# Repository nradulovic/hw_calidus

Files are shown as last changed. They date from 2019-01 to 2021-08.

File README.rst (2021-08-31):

.. contents:: Table of Contents
   :depth: 3

Introduction
============

This document shall describe rationales used to design and build audio
power amplifier using TDA7293 integrated circuit.

Architecture
============

The amplifier architecture consists of the following sections:

* Input section
* Output section
* Power amplifier with power supply and Control and Monitoring Unit (CMU)

Input section
=============

Input EMI suppression
---------------------

To protect the input from EMI we will use the following Zobel network:

.. code::
          o Positive input or negative input
          |
          |
        ----- Czi
        -----
          |
          |
         +-+  Rzi
         | |
         | |
         +-+
          |
         === Ground

For most input cables characteristic impedance falls in range between
50 and 100ohm impedance and we are using the 75ohm as the middle value. The
resistor Rzi is ``Rzi=75ohm`` and the capacitor Czi is ``Czi=220pF``.
This network should be placed right at the input connector, not on the
main amplifier PCB.

Also, a 100n X7R capacitor shall be placed between SGND and chassis right at the
input connector. This capacitor will shunt radio and other interfirence signal
into the Chassis Ground potential.

Input low-pass filter
---------------------

For input filter we choose the frequency between 300kHz and 400kHz.

.. code::

        +---+ Rlp1    +---+ Rlp2
    0---+   +----+----+   +---+---o Toward Amplifier IC block
        +---+    |    +---+   |
               ----- Clp1   ----- Clp2
               -----        -----
                 |            |
                === Ground   === Ground

Using the 2nd order CR low-pass filter calculator at URL:
*http://sim.okawa-denshi.jp/en/CRCRtool.php* we arrive at:

.. math::

    Rlp1 = 100 Ohm, Rlp2 = 100 Ohm

    Clp1 = 220pF,   Clp2 = 2.2nF

    fp1 = 352kHz

    fp2 = 14MHz

For more details please refer to: http://www.johnhearfield.com/RC/RC4.htm

The ground loop breaker resistor
--------------------------------

A ground loop breaker resistor is located between SGND and GNDPWR grounds. The
value of this resistor should be around 10 ohms.

Power amplifier
===============

Output EMI suppression
----------------------

Output network consists of upstream and downstream Zobel Network and of output
coil (``Ld``) with parallel, damping resistor (``Rd``). Upstream Zobel network 
provides a low-inductance load for the output stage at very high frequencies 
and allows high-frequency currents to circulate local to the output stage. The 
downstream Zobel network provides a good resistive termination right at the 
speaker terminals at high frequencies, helping to reduce RFI ingress and damp
resonances with, or reflections from, the speaker cables.
The output circuit is the following:

.. code::

    Ld
             xxx
        +---x   x   x---+
        |        xxx    |
        |               |
        |   +-------+   |
    o---+---|       |---+---o
    Vout    +-------+   |   Vspeaker
        Rd              |
                      ----- Cz2 = 100nF
                      -----
                        |
                        |
                       +-+  Rz1 = 10 Ohm
                       | |
                       | |
                       +-+
                        |
                       ===

The output coil ``Ld`` provides high frequency isolation of output load from 
output stage in TDA7293. The inductance value should be between 2uH up to 5uH.
Output shunt resistor should be between 2 and 5 Ohms. See
*Douglas Self - Audio Power Amplifier Design Handbook, 3rd Ed., Output networks, chapter 7*
for effect on power amplifier transfer function.

Paralleling multiple modules
----------------------------

Power dissipation
`````````````````

NOTE:

* Try to keep power dissipation to around 40W per IC package.

Fortunately, with music signals the power dissipation should be lower.
Effective power of music signal is about 2 to 10 times as smaller than
effective power of sinusoid signal. The power transformer is 200VA, meaning
that each channel gets 100VA of power.

Maximum voltages at:
 * Maximum ``Pdiss=50W`` for TDA7293.
 * Load phase is ``LoadPHI=60degrees``.
 * Including quiescent current dissipation.
 * Case temperature is 60C degrees.
 * Taking into account OPS SOA.

+-------------+-------------+-----------+--------------+
| Zload [ohm] | Vsupply [V] | Vdrop [V] | Pdiss [W]    |
+-------------+-------------+-----------+--------------+
| 16          | 33          | 2.2       | 31.4         |
+-------------+-------------+-----------+--------------+
| 12          | 29          | 2.3       | 31.6         |
+-------------+-------------+-----------+--------------+
| 8           | 25          | 2.5       | 34.2         |
+-------------+-------------+-----------+--------------+
| 6           | 22          | 2.6       | 34.7         |
+-------------+-------------+-----------+--------------+
| 4           | 19          | 2.9       | 37.4         |
+-------------+-------------+-----------+--------------+

This table tells us that if we want to drive 4ohm load at 33V we need 4 pieces
of TDA7293 in parallel. This is quite a number of ICs, but fortunately, the
table presumes that the power supply can produce constant 33V at continuous
load and the signal is sinusoid. This is not the case with unregulated power
supply and music signals. We have to take into account how much energy is
stored in power supply capacitors and how much will the transformer voltages
sag under these conditions and that music signal has much lower effective power
comparing to instantaneous power.

Transformer specification for TDA7293 amplifier is the following:
 * ``S=200VA``, power rating.
 * ``Usn1=24Veff``, first secondary nominal voltage.
 * ``Usn2=24Veff``, second secondary nominal voltage.
 * ``k=5%``, regulation.

Secondary internal resistance is:

.. math::

    Usu=Usn1*(1+(k/100))

    Isn=S/(Usn1+Usn2)

    Ri=(Usn1-Usu)/Isn

Using values from above we get:

.. math::

    Usu=24*(1+(5/100))=25.2Veff

    Isn=4.17Aeff

    Ri=288mOhm

The power supply section is using single bank of 10mF capacitors.

Gain value
----------

Using inverted topology since we want to reduce common mode distortion in the
input stage. But in case of TDA7293 IC it is not easy to use inverted topology
since the mute circuit is implemented on positive OPAMP input.

The equivalent gain circuit resistance needs to stay below 600ohms. This is so
because all noise measurements in data-sheet were done with 600ohms or 0ohms.

Using low feedback gain is preferred for several reasons:
 * there is more loop gain available to reduce the distortion
 * reduced outout noues
 * lower offset at output

Nominal gain is:

.. math::

    G=-Rf/Rg

Using E24 series of resistors:

+-----------+-----------+---------+
| Rf [Ohm]  | Rg [kOhm] | G [V/V] |
+-----------+-----------+---------+
| 510       |  7.5      | -14.7   |
+-----------+-----------+---------+
| *510*     |  *8.2*    | *-16.0* |
+-----------+-----------+---------+
| 510       |  9.1      | -17.8   |
+-----------+-----------+---------+
| 510       | 10.0      | -19.6   |
+-----------+-----------+---------+
| 510       | 11.0      | -21.5   |
+-----------+-----------+---------+

Using E24 series of resistors:

+-----------+-----------+---------+
| Rf [Ohm]  | Rg [kOhm] | G [V/V] |
+-----------+-----------+---------+
| 511       |  7.50     | -14.7   |
+-----------+-----------+---------+
| 511       |  7.87     | -15.4   |
+-----------+-----------+---------+
| *511*     |  *8.25*   | *-16.1* |
+-----------+-----------+---------+
| 511       |  8.66     | -16.9   |
+-----------+-----------+---------+
| 511       |  9.09     | -17.8   |
+-----------+-----------+---------+
| 511       |  9.53     | -18.6   |
+-----------+-----------+---------+
| 511       | 10.00     | -19.6   |
+-----------+-----------+---------+
| 511       | 10.50     | -20.5   |
+-----------+-----------+---------+
| 511       | 11.00     | -21.5   |
+-----------+-----------+---------+

Chosen values for E24 series:
 * Rf = 8.2kOhm
 * Rg = 510 Ohm

Chosen values for E48 series:
 * Rf = 8.25kOhm
 * Rg = 511 Ohm

Chosen values when using parallel E24 series (two resistor):
 * Rf = 16kOhm
 * Rg = 1kOhm

Chosen values when using parallel E48 series (two resistor):
 * Rf = 16.2kOhm
 * Rg = 1kOhm

Frequency compensation
----------------------

The TDA7293 data-sheet does not provide enough of relevant data in order to
model the IC in AC domain. Since we can't model it there are no optimizations
available for the negative feedback circuit. But we can safely assume that
there are high frequency poles present in the TDA7293 transfer function. For
this reason we will add a few ``pF`` to calculated lead compensation
capacitor below (see ``Cadd``).

Lead compensation
`````````````````

Equivalent feedback network with lead compensation circuit::

          o Vout
          |
          *------+
          |      |
         +-+ Rf  |
         | |   ----- Cf=Cl (+Csi, see Input pin capacitance compensation)
         | |   -----
         +-+     |
   Vf     |      |
    o-----*------+
          |
         +-+ Rg
         | |
         | |
         +-+
          |
          o Input

Resistors `Rf` and `Rg` are part of feedback network. Capacitor `Cf` is the
compensation capacitor. The transfer function of this network is given as:

.. math::

    Vf(s)=I(s)*Rg

    Vout(s)=I(s)*(Rf||Cl + Rg)=I(s)*(Rf/(1+s*Rf*Cl)+Rg)

    H(s)=Vf(s)/Vout(s)=(Rg/(Rf+Rg))*((1+s*Rf*Cl)/(1+s*Re*Cl))

Zero:

.. math::

    wz=1/(Rf*Cl)

Pole:

.. math::

    wp=1/(Re*Cl)

Where:

.. math::

    Re=Rf||Rg=Rf*Rg/(Rf+Rg)

Rough estimation is to put additional 1-3pF in parallel to ``Rf``.

.. math::

	Cadd = 3pF

Input pin capacitance compensation
``````````````````````````````````

Input pins have the following parasitic capacitances associated:

* Cdiff
* Cm
* Cstray

The TDA7293 data-sheet does not specify any parameter regarding parasitic
input capacitances. Voltage feedback OPAMPS usually have both differential and
common-mode input impedances specified. In the absence of any information, it
is safe to use the model given in the next figure:

.. code::

                   +----+ Zdiff
    +input o---+---|    |---+---o -input
               |   +----+   |
               |            |
              +-+ Zcm1     +-+ Zcm2
              | |          | |
              | |          | |
              +-+          +-+
               |            |
              ===          ===

We can use a rough estimation of values based on experience on using other 
audio FET OPAMPS, and typical values are around ``Cdiff=5pF``, ``Cm=4pF`` 
and ``Cstray=3pF``. All three equivalent capacitors are tied in parallel, 
so the total input capacitance becomes:

.. math::

    Cinput = Cdiff+Cm+Cstray=5pF+4pF+3pF=12pF

To mitigate this capacitance we can add capacitance `Csi` parallel to `Rf`
resistor. To compensate for this the following equation is applied:

.. math::

    Rf*Cf=Rg*Cinput

    Csi=Cinput*Rg/Rf=0.5pF

The final ``Cf`` value is:

.. math::

    Cf=Cl+Csi+Cadd=0+2+0.5=2.5pF

Any NP0 based capacitor around ``3pF`` will be good for this purpose.

Power supply
============

Power amplifier power supply
----------------------------

We are using dual symmetrical supplies from since dual secondaries. The high
voltage supplies are stabilized using LM317/LM337 regulators and are used to
feed input sections of TDA7293.

The low voltage supplies are supplied directly from reservoir capacitors. This
supply powers the high current, high power output sections of TDA7293.

By using dual and independent supplies for input sections and power sections we
can achieve very good PSRR results.

Before rectifier diodes a snubber RC circuit should be placed to decrease diode
switching impulse. Recommended values are ``Rsn = 1 Ohm``, ``Csn = 470nF``::

          o Vsupply
          |
          |
        ----- Csn = 470nF
        -----
          |
          |
         +-+  Rsn = 1 Ohm
         | |
         | |
         +-+
          |
         === Ground

This snubber may be placed near the IC power supply lines, too.

AC mains
--------

NOTE:
 * On case chassis there should be a safety ground screw just near at the input
   220V socket.

Control and Monitoring Unit
===========================

Amplifier controller will control and monitor two amplifiers. It has the
following components:

* Power supply undervoltage protection
* Power supply overvoltage protection
* Power supply imbalance protection
* Output DC offset protection
* Output clipping protection
* Over-temperature protection
* Over-current protection

Power supply undervoltage protection
------------------------------------

Power supply overvoltage protection
-----------------------------------

Power supply imbalance protection
---------------------------------

Output DC offset protection
---------------------------

Output clipping protection
--------------------------

Over-temperature protection
---------------------------

Over-current protection
-----------------------

Analog inputs
-------------

.. code::

                o  Vdd
                |
               +-+
               | | R2
               | |
         R1    +-+
        +---+   |
    o---|   |---+------+---o Analog output (to MCU ADC)
        +---+   |      |
    Analog     +-+     |
    Input      | | R3 --- C1
               | |    ---
               +-+     |
                |      |
               ===    ===

Enviromental parametars:

* Power supply: Vdd = 5V
* Analog output impedance: Rout <= 10k

Specification:

* Analog input range: Ain = +/-40V
* Analog input impedance: Rin >= 10k

Equations:
 (1) Since for 0V Ain we need 2.5V Aout: R2 = R1 || R3
 (2) Since we need gain 1/16 (5V/80V) we have: 16 = R1 / (R1 || R2 || R3)

This give as two equations with 3 unknowns:

.. math::

    (1 - Gain - 1)*G1 + G2 + G3 = 0

    Vref * G1 + Vref * G2 + (Vref - Vhigh) * G3 = 0

With Gain = 16, Vreg = 2.5V and Vhigh = 5V we have:

.. math::

    -15G1+G2+G3=0

    2.5G1+2.5G2-2.5G3=0

Start with G3 = 1/10:

.. math::

    -15G1+G2=-0.1

    2.5G1+2.5G2=0.25

    G1=1.25e+3 => R1=80kOhm

    G3=8.75e-2 => R2=11.43kOhm

One possibility is to have:

.. math::

    R1 = 110kOhm

    R2 = 10kOhm

    R3 = 11kOhm

This combination has Gain = 22

Monitor PIC18F46K40/PIC18F26K40 MCU pins
----------------------------------------

+-----------------------+---------------+-----------+-----------+---------------------------------------------------+
| # / Signal name       | Type          | 40 pin    | 28 pin    | Description                                       |
+-----------------------+---------------+-----------+-----------+---------------------------------------------------+
| 1. pa_vcc             | analog in     | RD0       |           | Measures the VCC voltage                          |
+-----------------------+---------------+-----------+-----------+---------------------------------------------------+
| 2. pa_vee             | analog in     | RD1       |           | Measures the VEE voltage                          |
+-----------------------+---------------+-----------+-----------+---------------------------------------------------+
| 3. pa_ope             | analog in     | RA6       | RA6       | Measures Output Positive Envelope (Both channels) |
+-----------------------+---------------+-----------+-----------+---------------------------------------------------+
| 4. pa_one             | analog in     | RA7       | RA7       | Measures Output Negative Envelope (Both channels) |
+-----------------------+---------------+-----------+-----------+---------------------------------------------------+
| 5. pa_oal             | analog in     | RA2       | RA2       | Measures Output Average Left                      |
+-----------------------+---------------+-----------+-----------+---------------------------------------------------+
| 6. pa_oar             | analog in     | RA4       | RA4       | Measures Output Average Right                     |
+-----------------------+---------------+-----------+-----------+---------------------------------------------------+
| 7. pc_ol              | analog/comp in| RA0       | RA0       | Compares Output Left impedance                    |
+-----------------------+---------------+-----------+-----------+---------------------------------------------------+
| 8. pc_or              | analog/comp in| RA1       | RA1       | Compares Output Right impedance                   |
+-----------------------+---------------+-----------+-----------+---------------------------------------------------+
| 9. pc_ref             | analog/comp in| RA3       | RA3       | Comparator reference voltage                      |
+-----------------------+---------------+-----------+-----------+---------------------------------------------------+
| 10. pc_i2c_scl        | i2c scl       | RC3       | RC3       | Sensor network SCL                                |
+-----------------------+---------------+-----------+-----------+---------------------------------------------------+
| 11. pc_i2c_sda        | i2c sda       | RC4       | RC4       | Sensor network SDA                                |
+-----------------------+---------------+-----------+-----------+---------------------------------------------------+
| 12. pc_uart_rx        | uart rx       | RC7       | RC7       | Service terminal RX (from PIC perspective)        |
+-----------------------+---------------+-----------+-----------+---------------------------------------------------+
| 13. pc_uart_tx        | uart tx       | RC6       | RC6       | Service terminal TX (from PIC perspective)        |
+-----------------------+---------------+-----------+-----------+---------------------------------------------------+
| 14. po_comp_en        | dig out       | RA5       | RA5       | Enable comparator current sources                 |
+-----------------------+---------------+-----------+-----------+---------------------------------------------------+
| 15. po_ctrl_power     | dig out       | RB1       | RB1       | Control power relay                               |
+-----------------------+---------------+-----------+-----------+---------------------------------------------------+
| 16. po_ctrl_pbypass   | dig out       | RB2       | RB2       | Control power bypass relay                        |
+-----------------------+---------------+-----------+-----------+---------------------------------------------------+
| 17. po_ctrl_mute      | dig out       | RB3       | RB3       | Control mute relay                                |
+-----------------------+---------------+-----------+-----------+---------------------------------------------------+
| 18. po_ctrl_enable    | dig out       | RB4       | RB4       | Control power amplifier enable                    |
+-----------------------+---------------+-----------+-----------+---------------------------------------------------+
| 19. po_ind_power_a    | dig out       | RB5       | RB5       | Indicator power/status LED, pin A                 |
+-----------------------+---------------+-----------+-----------+---------------------------------------------------+
| 20. po_ind_power_b    | dig out       | RD2       |           | Indicator power/status LED, pin B                 |
+-----------------------+---------------+-----------+-----------+---------------------------------------------------+
| 21. po_ind_overload   | dig out       | RB6       | RB6       | Indicator overload LED                            |
+-----------------------+---------------+-----------+-----------+---------------------------------------------------+
| 22. po_status         | dig out       | RB7       | RB7       | Status LED on board                               |
+-----------------------+---------------+-----------+-----------+---------------------------------------------------+
| 23. pi_key_power      | dig in        | RB0       | RB0       | Power key                                         |
+-----------------------+---------------+-----------+-----------+---------------------------------------------------+
| 24. pi_key_mute       | dig in        | RC5       | RC5       | Mute key                                          |
+-----------------------+---------------+-----------+-----------+---------------------------------------------------+
| 25. pi_det_ac_power   | dig in        | RC0       | RC0       | AC power detection                                |
+-----------------------+---------------+-----------+-----------+---------------------------------------------------+
| 26. pi_det_overload   | dig in        | RC1       | RC1       | Overload detection                                |
+-----------------------+---------------+-----------+-----------+---------------------------------------------------+
| 27. pi_det_signal     | dig in        | RC2       | RC2       | Signal detection                                  |
+-----------------------+---------------+-----------+-----------+---------------------------------------------------+
| 28. pi_cfg_power      | dig in        | RD3       |           | Configure power control mode                      |
+-----------------------+---------------+-----------+-----------+---------------------------------------------------+
| 29. pi_cfg_ac_power   | dig in        | RD4       |           | Configure AC power detection mode                 |
+-----------------------+---------------+-----------+-----------+---------------------------------------------------+
| 30. pi_cfg_impedance  | dig in        | RD5       |           | Configure Impedance monitoring mode               |
+-----------------------+---------------+-----------+-----------+---------------------------------------------------+
| 31. pi_cfg_sensors    | dig in        | RD6       |           | Configure sensors mode                            |
+-----------------------+---------------+-----------+-----------+---------------------------------------------------+
| 32.                   |               | RD7       |           |                                                   |
+-----------------------+---------------+-----------+-----------+---------------------------------------------------+
| 33.                   |               | RE0       |           |                                                   |
+-----------------------+---------------+-----------+-----------+---------------------------------------------------+
| 34.                   |               | RE1       |           |                                                   |
+-----------------------+---------------+-----------+-----------+---------------------------------------------------+
| 35.                   |               | RE2       |           |                                                   |
+-----------------------+---------------+-----------+-----------+---------------------------------------------------+

Hardware configurations
-----------------------

Power control mode

* 0 - Disabled, always on
* 1 - Enabled, wait for Power on event

AC power detection mode:

* 0 - Disabled, AC always present
* 1 - Enabled, AC detect on

Impedance monitoring mode:

* 0 - Disabled, always allow power on
* 1 - Enabled, dissallow power on when impedance is out of minimal limit

Sensors mode:

* 0 - Disabled, all temperature sensors are ignored
* 1 - Enabled, read all temperature sensors

Software configurations
-----------------------

Power supply:

* nominal value: 20V
* minimal value: 15V
* maximum value: 25V
* imbalance value: 10V
* bypass time: 500ms
* post bypass time: 500ms
* mode, same as HW configuration 1

Clipping detector:

* clipping min voltage 4: 5
* clipping min voltage 8: 3
* hold off: 1000ms
* timeout to mute: 10s
* timeout to shutdown: 20s
* mode:

  * 0 - Disabled,
  * 1 - Enabled

AC detector:

* num of cycles missing: 4
* mode, same as HW configuration 2

Impedance detector:

* mode, same as HW configuration 3

Temperature detector:

* mode

Chassis
=======

Component height
----------------

Power supply capacitors on amplifier boards:

* 30mm (10mF)

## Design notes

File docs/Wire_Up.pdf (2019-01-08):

# How to Wire up an Audio Power Amplifier for Zero Noise Problems

# www.hifisonix.com

### Andrew C. Russell

Updated March 2014

1

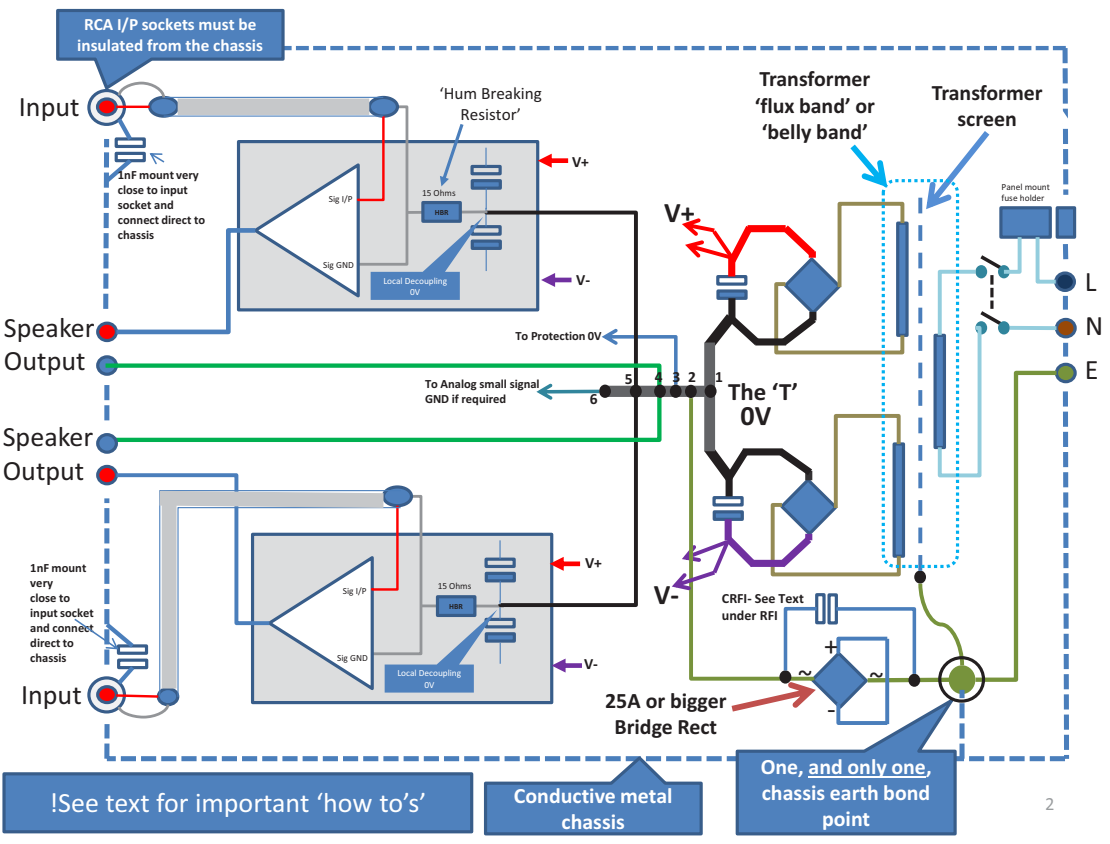
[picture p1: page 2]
The ‘T’; 15 Ohms; Local Decoupling 0V; Sig GND; Sig I/P; point; Transformer screen; Panel mount fuse holder; Input; Speaker Output; 25A or bigger Bridge Rect; 1nF mount very close to input socket and connect direct to chassis; Conductive metal chassis; To Protection 0V; HBR; ‘Hum Breaking Resistor’

RCA I/P sockets must be
insulated from the chassis

Transformer
‘flux band’ or
‘belly band’

1nF mount very
close to input
socket and
connect direct to
chassis

To Analog small signal
GND if required

CRFI- See Text
under RFI

One, and only one,
chassis earth bond

!See text for important ‘how to’s’

# Achieving ‘Zero Noise’ is Easy if You

Follow These Basic Rules • Mains wires to the fuse, switch and to the transformer primary are tightly twisted* together

- Transformer wires from each secondary to its associated bridge rectifier are tightly twisted

## together

- Wires from each bridge rectifier to their associated filter capacitor(s) are tightly twisted

## together

- The V+, V- and 0V to each of the amplifier boards are twisted tightly together. These wires

## come directly off the filter capacitors – note carefully how this is drawn in the diagram

- Keep the speaker output wire from the amplifier board to the output terminal as short as

## practical

- Keep the speaker return wire from the speaker socket back to the ‘T’ as short as possible. Ideally, you should twist the speaker + and – cables together, but this is usually difficult in practice due to layout limitations.
- There is only ONE and only ONE chassis bond point in the amplifier – multiple bond points run the risk of creating earth loops. Make sure it’s a high quality connection – use serrated washers

## and lock nuts and ensure they are tight. Use a meter to check that all parts of the metal

chassis connect to this bond point.

## - The input or output sockets may NOT make any direct connection to the metal chassis - Keep high current wires away from small signal wires

- Use a ‘HBR’ resistor (that’s the 15 Ohms devices you see in the previous slide) to prevent significant ground currents flowing between the source device and receiving amplifier. The signal ground connects to the amplifier on-board ground through this resistor.
* Twin wires also work, though not as well as twisting | 3

# How to Order the ‘T’ – its Important for Low Noise

# - Note carefully the order to the ‘T’ section – from right to left on the diagram

## 1. filter capacitor junction 2. Take off point to earth bond connection 3. Any protection circuits or digital signal boards 4. Speaker returns – these are high current 5. Decoupling and small signal Amplifier module/PCB 0V 6. Any small signal analog board – e.g. preamplifier stage(s)

# - The total length of the ‘I’ in the ‘T’ need not be longer than 3~4 centimeters – 1-2 cm is adequate - Keep the top bar the T as short as possible – to do this, mount the filter caps right next to each other

- See the next page for how to do these things practically.

4

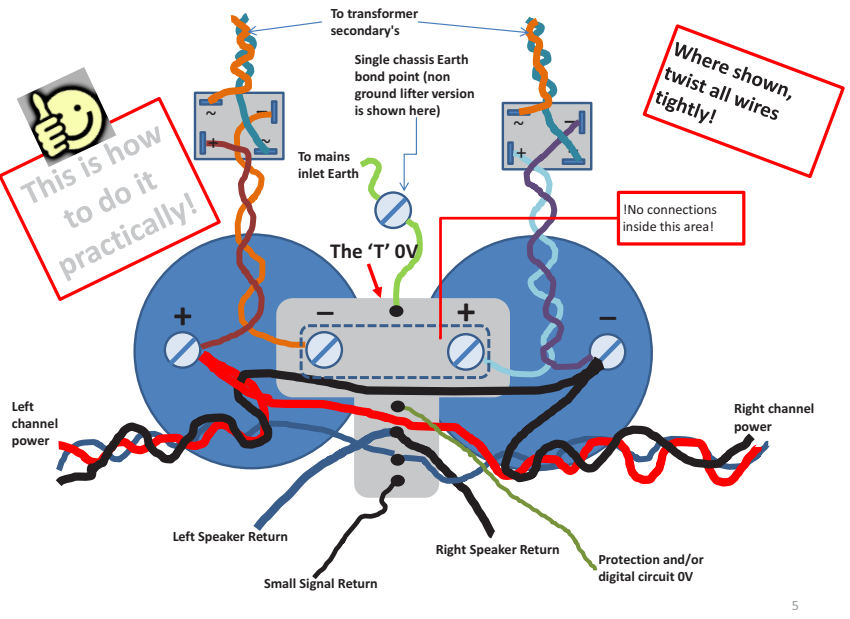
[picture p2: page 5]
Left channel power; Right channel power; Right Speaker Return; Protection and/or; To transformer secondary's; The ‘T’ 0V; To mains inlet Earth

Single chassis Earth
bond point (non
ground lifter version
is shown here)

!No connections
inside this area!

Left Speaker Return

digital circuit 0V Small Signal Return

## General Rules • Keep input wiring away from output wiring

## - Keep mains wiring away from all other wiring

- Keep the secondary connections to the rectifiers and capacitors as short as possible, and away from other wiring.
- Use good quality screened cable for the input socket to amplifier board connection. Cheap cable simply bundles the ‘screen’ with the core with no twist which offers less than adequate protection against noise (see next page for comments on RFI). Good quality screen cable has a tight woven screen. If you do not have screened cable, tightly twist the signal and ground

## wire – this can be very effective as well. Keep the input wiring well away from any high current wiring

## - Twisting the feed and return wires between transformer, rectifiers, smoothing caps and

amplifier modules minimizes the radiating area, and thus noise emissions.
- You will note a 15 Ohm resistor in the amplifier module between the signal ground and the amplifier module 0V.

– This resistor ensures that equipment plugged into the amplifier input does not cause earth loop currents to flow in the small signal ground of the amplifier PCB, to the PSU star ground and then to the chassis. With this arrangement, the earth currents (fault and normal leakage) are forced to flow in the earth (i.e. ground) wires. This technique is very effective in reducing hum caused by earth loops – up to 20dB is not uncommon

## - ALL equipment should have a solid chassis connection to earth/ground through the mains

earth wire. This is critical for electrical safety and is also a legal requirement.

– However, double insulated consumer equipment that only use 2 pin mains connection is typically found in North America and some Asian countries. The techniques described above work on this type of equipment as well – i.e. you can still achieve ‘zero noise’

6

# RFI

## - Wire 1nF ceramic capacitor from the input socket 0V to the chassis as close to the input socket as possible. At RF, this connects the cable screen to the chassis as it enters the housing. Any RFI picked up by the interconnect cable or impinging on

the amplifier housing is shunted to ground reducing susceptibility to RFI.

## - In some designs, you may get better immunity by fitting a 10nF capacitor Ccomp across the AC terminals of the ground lifer bridge rectifier. This shunts any residual

RF on the chassis coming in through the input cables to earth.

## - You can test your amplifier immunity once fully assembled with all the panels screwed in by placing your mobile phone on top of your amplifier and then getting a friend to call you. You should hear no buzzing or extraneous noises over

your speakers.

- Always ensure you have a band limiting filter on the input of your amplifier. 1k and 220pf is a good compromise. If you are worried about thermal noise, 220 Ohms and 1nF is also ok. But, whatever you do, make sure you have the filter - Good quality interconnects (tightly woven screen, gold plated plugs and sockets) also help prevent RFI problems

7

# If You Get it Right, Here Are the Results You Should Expect

# - With no inputs plugged into your amplifier, you should see no more than about 200uV pk-pk noise on the output – for a ~100W amplifier, that translates to better than -105 dB noise. If you do a really good job, you can expect half this level, or about 100uV or about -110 dB

- With a preamp plugged in and powered up with volume set to minimum,

# assuming it is correctly wired up, the noise should not exceed 500uV pk-pk – that’s still about -100 dB

# - With the preamp plugged in, but powered OFF, the noise level should be

-105 dB.

# Happy Listening!

8

Zero Noise Audio Amplifier FAQ’s • | I read that you need a balanced input for good noise rejection performance
– | You can achieve ~-110 dB with good wiring on single ended input amplifiers. Balanced inputs are necessary in professional applications where electrical noise levels are usually much higher. For domestic applications, single ended is ample for most applications

### - Why do you show a ‘screen’ on your transformer and what does it do?

– A capacitance exists between the primary and secondary of a transformer. In a toroid, it is much higher than in a E core or R core. This capacitance couples mains noise from the primary side onto the secondary. The screen is located between the primary and secondary and connects the inter-winding capacitance to GND, effectively shunting the mains noise to ground as well. This technique can deliver 20~30 dB noise reduction if executed correctly and save on the cost of the mains filter.

- What kind of mains power socket (i.e. mains inlet receptacle) do you recommend for the power inlet.
– For DIY, always use a switched, fused IEC 3PIN socket. Here is a link to a suitable one from mouser: mains entry socket These types of sockets are safe, incorporate the very important fuse and a switch. Note, if you shop around, you can get good quality inlets for about $7.

### - What is a flux band (aka a ‘belly band’) and what does it do?

– A belly band is a thin metal overwrap that goes around the outside of a transformer (E core or toroid). It is very effective in reducing the radiated field from the transformer, and thus in reducing noise. If your transformer is wound with a screen and a belly band, it is possible to get very good noise performance. I recommend that you always specify both if you have a transformer custom wound

- Why do you have separate rectifiers on each of the secondaries going to capacitors. What’s going on with that

### part of the circuit? Aren't you wasting a rectifier like this?

– By rectifying and smoothing and only then combining the secondaries you almost guarantee that the capacitor charging currents – which In a big amplifier can be as high as 50~100A – are kept out of the small signal ground returns through common impedance coupling . However, do also note that you must ‘T’ off as shown in page 2 to get the full benefit of this approach. If you simply connect all the wires to the top of the ‘T’ you will probably introduce noise. As a further step, you can phase the secondaries so that their fields partially cancel, reducing noise

### - How can I phase the secondaries?

– Wrap 5 turns of insulated wire around your transformer. Connect the two ends to a pair of headphones. Listen to the sound. Then swap the connections around between the secondary and its associated bridge rectifier on one of the secondaries. If the noise is louder, return the secondary connections to how they were previously, otherwise leave them as is. Its that simple.

### - What does the ‘HBR’ resistor do?

– It prevents high ground loop currents flowing through the interconnects, and forces them instead to flow through the chassis earth connections via the mains inlet receptacle. This approach can reduce amplifier hum substantially.

9

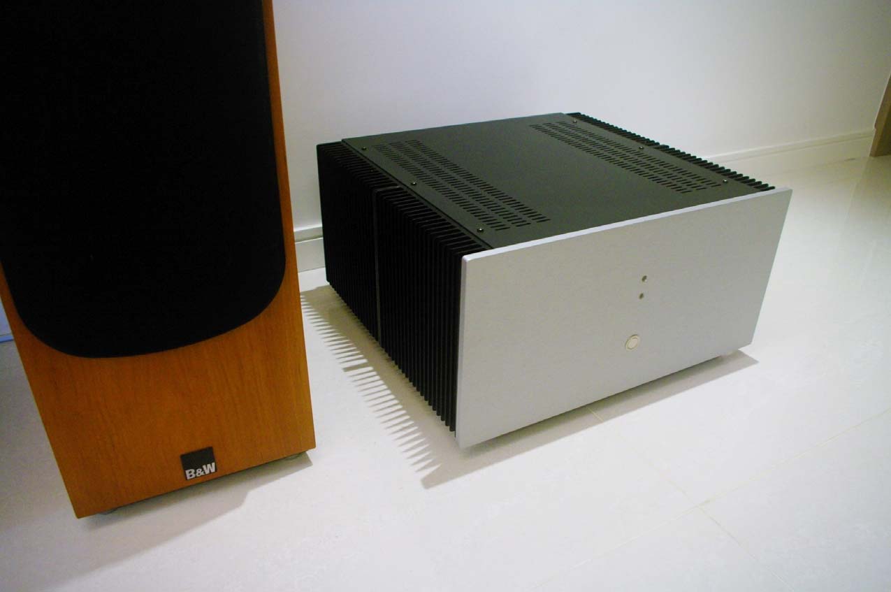
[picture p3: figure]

180 W RMS per channel ‘e-Amplifier’ featuring VFA topology, 10ppm 20 kHz distortion and peak output currents of ~40A, 3 Hz to 200 kHz bandwidth, and better than -100dB noise and hum ref 2.8V peak output into 8 Ohms that uses the wiring techniques described in this document.

10

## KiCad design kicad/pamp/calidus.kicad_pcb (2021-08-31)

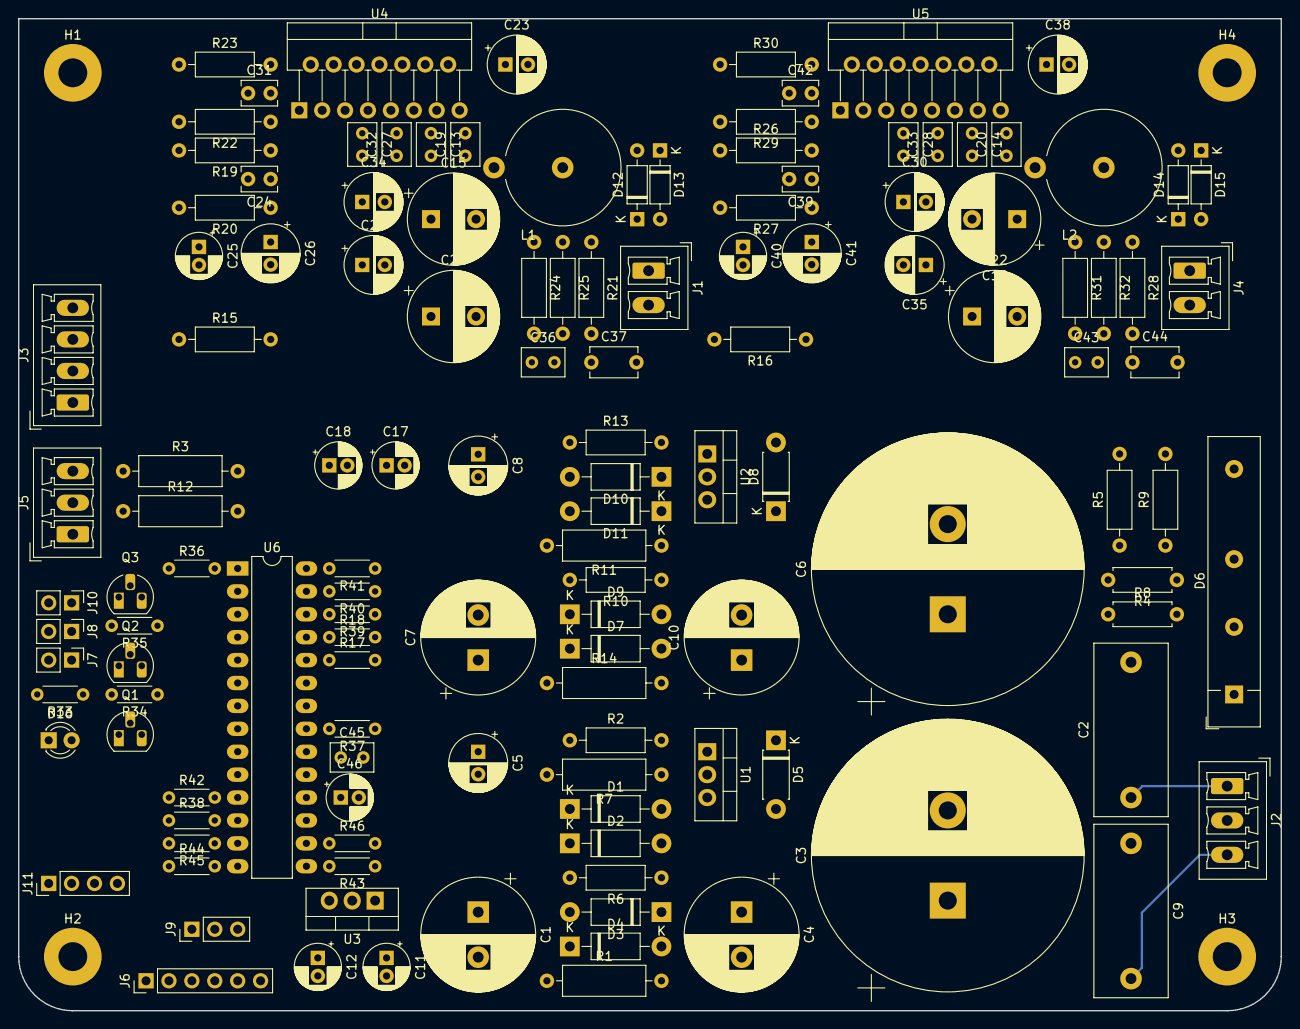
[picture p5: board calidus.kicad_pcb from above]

Board: 4 copper layers, 140.0 x 110.0 mm, 134 parts (0 on the bottom side), 70 nets.

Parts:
C1, C4, C7, C10: 470u; CP_Radial_D12.5mm_P5.00mm
C2, C9: 220n; C_Rect_L19.0mm_W8.0mm_P15.00mm_MKS4
C3, C6: 10m; CP_Radial_D30.0mm_P10.00mm_SnapIn
C5, C8, C23, C29, C30, C34, C35, C38: 47u; CP_Radial_D6.3mm_P2.50mm
C11, C12, C17, C18, C25, C40, C46: 10u; CP_Radial_D5.0mm_P2.00mm
C13, C14, C19, C20, C27, C28, C32, C33, C36, C43, C45: 100n; C_Rect_L4.6mm_W3.0mm_P2.50mm_MKS02_FKP02
C15, C16, C21, C22: 220u; CP_Radial_D10.0mm_P5.00mm
C24, C39: 220p; C_Disc_D3.8mm_W2.6mm_P2.50mm
C26, C41: 220u; CP_Radial_D6.3mm_P2.50mm
C31, C42: 3p3; C_Disc_D3.8mm_W2.6mm_P2.50mm
C37, C44: 100n; C_Disc_D5.1mm_W3.2mm_P5.00mm
D1, D11: BZX85C20; D_DO-41_SOD81_P10.16mm_Horizontal
D2, D3, D4, D7, D9, D10: 1N4007; D_DO-41_SOD81_P10.16mm_Horizontal
D5, D8: MBR1100RLG; D_DO-41_SOD81_P7.62mm_Horizontal
D6: D_Bridge_+A-A; Diode_Bridge_32.0x5.6x17.0mm_P10.0mm_P7.5mm
D12, D13, D14, D15: 1N5404; D_DO-35_SOD27_P7.62mm_Horizontal
D16: LED; LED_D3.0mm
H1, H2, H3, H4: Mounting; MountingHole_3.2mm_M3_Pad
J1: left_out; PhoenixContact_MCV_1,5_2-G-3.81_1x02_P3.81mm_Vertical
J2: power; PhoenixContact_MCV_1,5_3-G-3.81_1x03_P3.81mm_Vertical
J3: input; PhoenixContact_MCV_1,5_4-G-3.5_1x04_P3.50mm_Vertical
J4: right_out; PhoenixContact_MCV_1,5_2-G-3.81_1x02_P3.81mm_Vertical
J5: prevs; PhoenixContact_MCV_1,5_3-G-3.5_1x03_P3.50mm_Vertical
J6: icsp; PinHeader_1x06_P2.54mm_Vertical
J7: mute_key; PinHeader_1x02_P2.54mm_Vertical
J8: led_overload; PinHeader_1x02_P2.54mm_Vertical
J9: service; PinHeader_1x03_P2.54mm_Vertical
J10: led_power; PinHeader_1x02_P2.54mm_Vertical
J11: sense_bus; PinHeader_1x04_P2.54mm_Vertical
L1, L2: 4u; L_Axial_L20.3mm_D12.7mm_P7.62mm_Vertical_Vishay_IHA-201
Q1, Q2, Q3: Q_NPN_CBE; TO-92_HandSolder
R1, R3, R12, R14: 47; R_Axial_DIN0309_L9.0mm_D3.2mm_P12.70mm_Horizontal
R2, R13: 120; R_Axial_DIN0207_L6.3mm_D2.5mm_P10.16mm_Horizontal
R4, R8: 1; R_Axial_DIN0207_L6.3mm_D2.5mm_P7.62mm_Horizontal
R5, R9: 10k; R_Axial_DIN0207_L6.3mm_D2.5mm_P10.16mm_Horizontal
R6, R10: 30k; R_Axial_DIN0207_L6.3mm_D2.5mm_P10.16mm_Horizontal
R7, R11: 3k3; R_Axial_DIN0309_L9.0mm_D3.2mm_P12.70mm_Horizontal
R15, R16, R25, R32: 10; R_Axial_DIN0207_L6.3mm_D2.5mm_P10.16mm_Horizontal
R17, R18: 20k; R_Axial_DIN0204_L3.6mm_D1.6mm_P5.08mm_Horizontal
R19, R23, R26, R30: 12k; R_Axial_DIN0207_L6.3mm_D2.5mm_P10.16mm_Horizontal
R20, R22, R27, R29: 499; R_Axial_DIN0207_L6.3mm_D2.5mm_P10.16mm_Horizontal
R21, R24, R28, R31: 3.9; R_Axial_DIN0207_L6.3mm_D2.5mm_P10.16mm_Horizontal
R33, R34, R35: 620; R_Axial_DIN0204_L3.6mm_D1.6mm_P5.08mm_Horizontal
R36, R37, R38, R39, R40, R41, R45, R46: 10k; R_Axial_DIN0204_L3.6mm_D1.6mm_P5.08mm_Horizontal
R42: 100k; R_Axial_DIN0204_L3.6mm_D1.6mm_P5.08mm_Horizontal
R43, R44: 2k4; R_Axial_DIN0204_L3.6mm_D1.6mm_P5.08mm_Horizontal
U1: LM317; TO-220-3_Vertical
U2: LM337; TO-220-3_Vertical
U3: L7805; TO-220-3_Vertical
U4, U5: TDA7293; TO-220-15_P2.54x2.54mm_StaggerOdd_Lead4.58mm_Vertical
U6: PIC18F26K42-I/SP; DIP-28_W7.62mm_LongPads

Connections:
+pdvs: C12.1, C45.1, C46.1, D16.2, J6.2, J7.1, J8.1, J10.1, J11.4, R36.1, R37.1, R38.1, R43.1, R44.1, U3.3, U6.20
+prevs: J5.3, R3.1
+pwvs: C3.1, C11.1, C13.1, C14.1, C15.1, C16.1, D5.2, D6.1, D12.1, D14.1, R3.2, R5.1, U3.1, U4.13, U5.13
+vs: C5.1, C27.1, C28.1, C29.1, C30.1, D1.2, D2.2, D5.1, R2.1, U1.2, U4.7, U5.7
-prevs: J5.1, R12.1
-pwvs: C6.2, C19.2, C20.2, C21.2, C22.2, D6.3, D8.1, D13.2, D15.2, R9.2, R12.2, U4.15, U5.15
-vs: C8.2, C32.2, C33.2, C34.2, C35.2, D8.2, D10.1, D11.1, R13.2, U2.3, U4.8, U5.8
/Control and Monitoring Unit/ac_in: C9.2, D6.2, J2.3, R14.2, R42.1
/Control and Monitoring Unit/i2c_scl: J11.2, R44.2, U6.14
/Control and Monitoring Unit/i2c_sda: J11.3, R43.2, U6.15
/Control and Monitoring Unit/icspclk: J6.5, R40.2, U6.27
/Control and Monitoring Unit/icspdat: J6.4, R41.2, U6.28
/Control and Monitoring Unit/icsprst: J6.1, R36.2, U6.1
/Control and Monitoring Unit/mute: R17.1, U6.24
/Control and Monitoring Unit/mute_key: J7.2, R46.1, U6.16
/Control and Monitoring Unit/overload: R38.2, U4.5, U5.5, U6.12
/Control and Monitoring Unit/overload_led: J8.2, R34.2
/Control and Monitoring Unit/power_led: J10.2, R33.2
/Control and Monitoring Unit/stby: R18.1, U6.25
/Control and Monitoring Unit/uart_rx: J9.3, U6.18
/Control and Monitoring Unit/uart_tx: J9.2, U6.17
/pamp/in_l: C25.2, J3.4
/pamp/in_r: C40.2, J3.2
/pamp/out_l: J1.1, L1.2, R21.1, R25.1
/pamp/out_r: J4.1, L2.2, R28.1, R32.1
/psupply/pri_hi: C2.1, D6.4, J2.1, R1.2
Earth_Protective: C3.2, C4.2, C5.2, C6.1, C7.1, C8.1, C11.2, C12.2, C13.2, C14.2, C15.2, C16.2, C17.2, C18.2, C19.1, C20.1, C21.1, C22.1, C27.2, C28.2, C29.2, C30.2, C32.1, C33.1, C34.1, C35.1, C36.2, C37.2, C43.2, C44.2, C45.2, C46.2, D4.2, D7.1, J1.2, J2.2, J4.2, J5.2, J6.3, J9.1, J11.1, Q1.3, Q2.3, Q3.3, R4.2, R5.2, R6.2, R7.2, R8.1, R9.1, R10.1, R11.1, R15.2, R16.2, R45.2, R46.2, U3.2, U4.1, U5.1, U6.8, U6.19
unnamed: C1.1, D3.2, D4.1
unnamed: C1.2, R1.1
unnamed: C2.2, R4.1
unnamed: C4.1, D1.1, D2.1, D3.1, R6.1, U1.3
unnamed: C7.2, D9.2, D10.2, D11.2, R10.2, U2.2
unnamed: C9.1, R8.2
unnamed: C10.1, R14.1
unnamed: C10.2, D7.2, D9.1
unnamed: C17.1, R18.2, U4.9, U5.9
unnamed: C18.1, R17.2, U4.10, U5.10
unnamed: C23.1, U4.6
unnamed: C23.2, U4.12
unnamed: C24.1, R19.1, R20.1, U4.3
unnamed: C25.1, R20.2
unnamed: C26.1, R22.2
unnamed: C31.1, D12.2, D13.1, L1.1, R21.2, R23.2, R24.1, U4.14
unnamed: C31.2, R22.1, R23.1, U4.2
unnamed: C36.1, R24.2
unnamed: C37.1, R25.2
unnamed: C38.1, U5.6
unnamed: C38.2, U5.12
unnamed: C39.1, R26.1, R27.1, U5.3
unnamed: C40.1, R27.2
unnamed: C41.1, R29.2
unnamed: C42.1, D14.2, D15.1, L2.1, R28.2, R30.2, R31.1, U5.14
unnamed: C42.2, R29.1, R30.1, U5.2
unnamed: C43.1, R31.2
unnamed: C44.1, R32.2
unnamed: D16.1, R35.2
unnamed: Q1.1, R33.1
unnamed: Q1.2, R39.1
unnamed: Q2.1, R34.1
unnamed: Q2.2, R40.1
unnamed: Q3.1, R35.1
unnamed: Q3.2, R41.1
unnamed: R2.2, R7.1, U1.1
unnamed: R11.2, R13.1, U2.1
unnamed: R37.2, U6.21
unnamed: R39.2, U6.26
unnamed: R42.2, U6.11
unnamed: R45.1, U6.13
gnds_l: C24.2, C26.2, J3.3, R15.1, R19.2, U4.4
gnds_r: C39.2, C41.2, J3.1, R16.1, R26.2, U5.4

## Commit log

2019-01-08 Added PSU capacitor models.
2019-01-11 Created new project and schematics.
    [calidus.kicad_pcb, calidus.sch, pamp.sch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]
2019-01-13 Upgraded power supply
    Using new power supply design with 3pin linear regulator
    [pamp.sch, psupply.sch]
2019-01-22 Update of the schematic
    [calidus.sch, cmu.sch, pamp.sch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]
2019-01-22 Daily update
    [calidus.sch, cmu.sch, pamp.sch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]
2019-01-23 Updated component designators and finished CMU
    [calidus.sch, cmu.sch, pamp.sch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]
2019-01-24 Updated schematic and footprinted Rybicon capacitors
    [calidus.sch, pamp.sch, preamp.sch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]
2019-01-24 Annotated the schematic
    [pamp.sch, preamp.sch, psupply.sch]
2019-01-25 WIP: Updated footprints
    [cmu.sch, pamp.sch, preamp.sch]
2019-01-29 WIP: component footprint assignment.
    [calidus.kicad_pcb, calidus.sch, cmu.sch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]
2019-01-29 WIP: Component placement on PCB
    [calidus.kicad_pcb, calidus.sch, cmu.sch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]
2019-01-29 WIP: Removed unnecessary heatsinks
    [calidus.kicad_pcb, psupply.sch]
2019-01-29 WIP: Component placement
    [calidus.kicad_pcb, cmu.sch, pamp.sch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]
2019-01-30 WIP: Component placement and footpring assignment
    [calidus.kicad_pcb, calidus.sch, pamp.sch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]
2019-01-30 WIP: Component placement and footprint assignement
    - Finished all capacitors
    - Finished all ICs
    [calidus.kicad_pcb, cmu.sch, pamp.sch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]
2019-01-30 WIP: Minor placement adjustements
    [calidus.kicad_pcb]
2019-01-30 WIP: Component placement.
    [calidus.kicad_pcb]
2020-04-22 Added parallel TDA7293 implementation.
    [parvus_hamp.kicad_pcb, parvus_hamp.sch]
2021-08-31 chore: project update
    [calidus.kicad_pcb]
